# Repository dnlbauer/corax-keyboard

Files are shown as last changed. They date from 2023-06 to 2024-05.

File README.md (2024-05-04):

# Corax: A column-staggered fully-wireless split keyboard with scrollwheels.

- Choc-spaced, hot-swappable
- Two versions: with 56 or 54 keys
- Scrollwheel (EVQWGD001) on both sides
- Strong pinky stagger (0.66) and a 5 deg. pinky splay
- Fully wireless built for Nice!Nano + ZMK (no TRRS Jack)
- Nice!View support (5 pin connector)
- Reversible PCB
- 3d printable magnetic case, switchplate and MCU cover 

## Gallery

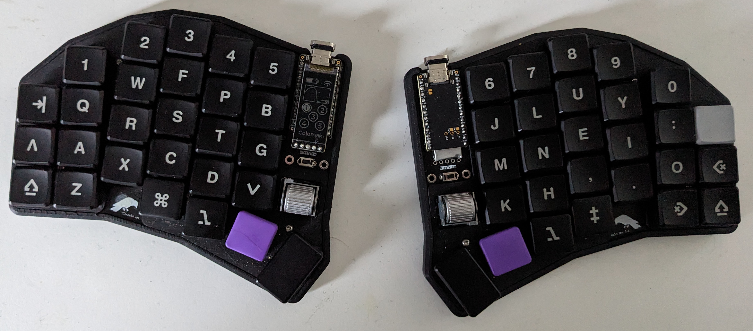
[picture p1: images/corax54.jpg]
corax54

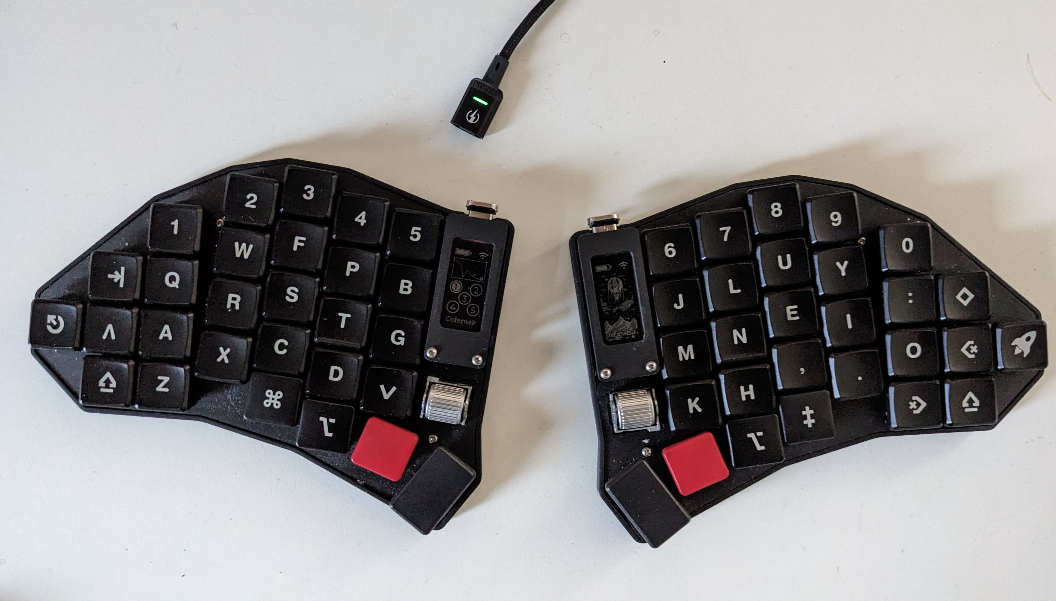
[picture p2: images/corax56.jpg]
corax56

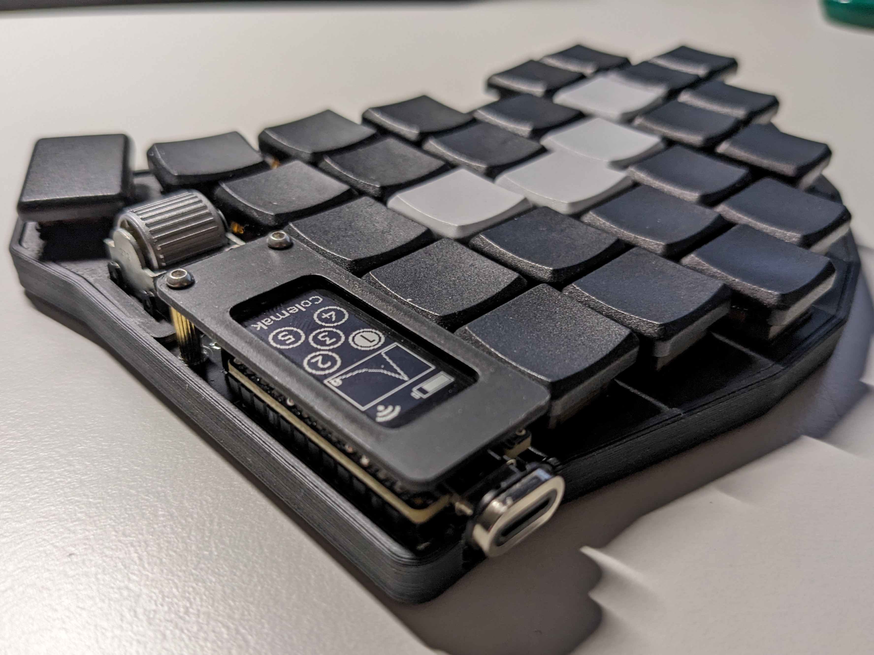
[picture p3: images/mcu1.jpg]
mcu1

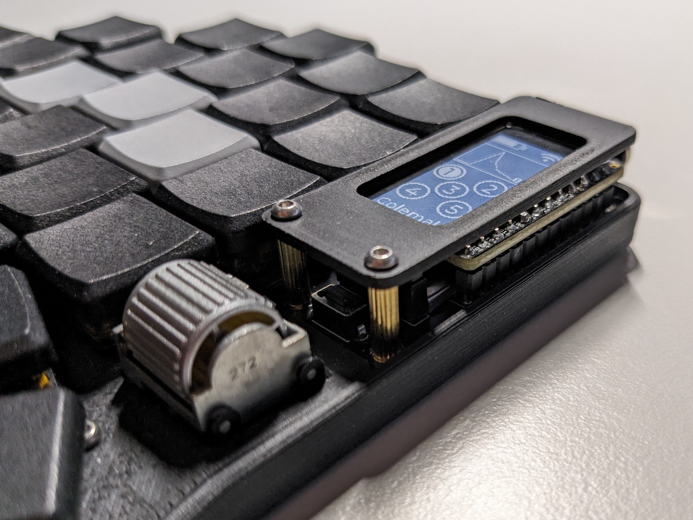
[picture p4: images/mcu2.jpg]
mcu2

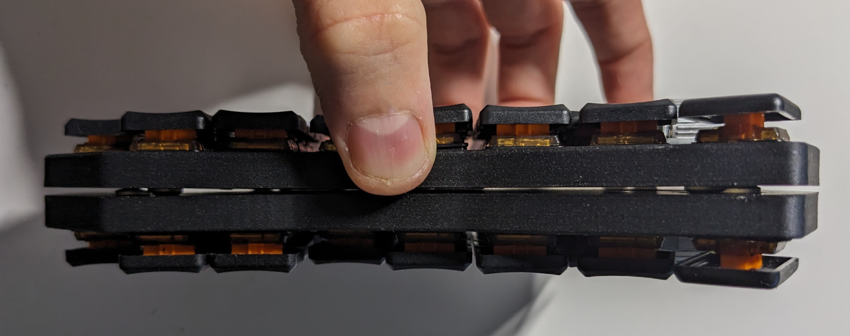
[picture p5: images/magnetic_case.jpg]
case

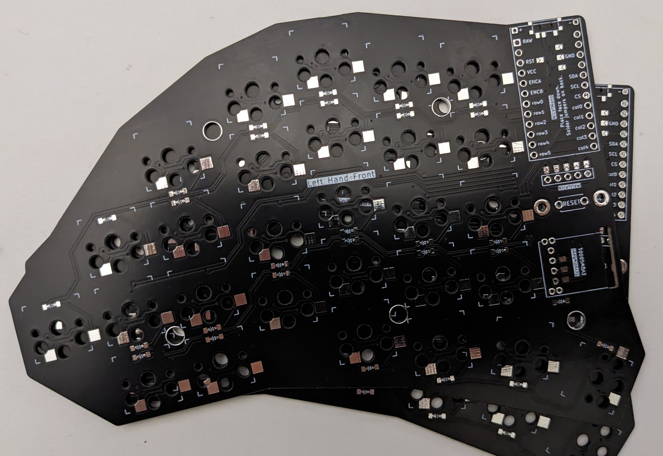
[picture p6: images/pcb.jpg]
pcb


## Corax56 vs Corax54

I initially designed the Corax56 (=56 keys) with 4 pinky keys. The upper key (usually mapped to ESC) was placed in a new column because I found it easier to reach horizontally than vertically.
Over the time, I realized that I am not using this button very often. The Corax54 was born as a more compact version where the pinky cluster misses this additonal column and has only 54 keys (2 less). This is the only difference between the two versions.

## Firmware

Natively supports [ZMK](https://zmk.dev/). The firmware for the Corax56 and Corax56 can be found in the submodule and is available here: https://github.com/dnlbauer/corax-zmk-config

## Build guide

[see here](./docs/BuildGuide.md)

## Standing on the shoulders of giants

- A great tutorial I referenced a lot by FlatFootFox: https://flatfootfox.com/ergogen-introduction/
- Lots of inspiration and ideas for this project came from these boards: [Choccy](https://github.com/sprengboard/choccy), [Sofle](https://github.com/josefadamcik/SofleKeyboard), [brain](https://github.com/Wesztman/brain), [spleeb](https://github.com/chrishoage/spleeb)

## License

This project is licensed under the MIT License - see the [LICENSE](LICENSE) file for details.

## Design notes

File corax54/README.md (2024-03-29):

# Corax54

## Bill of materials

**Essentials**:
| **Item** | **Count** | **Note** |
|---|---|---|
| Keyboard PCB | 2 | |
| Nice!Nano | 2 | |
| 12 pin headers and sockets | 4 | You can use through-hole diode legs as pins. Sockets spacing: 2.54mm, Socket height: Using minimal height sockets might not leave enough room to mount the battery under the MCU. 3DS1002-01-1*20V13-JK by CONNFLY are a good choice, but you can also use lower ones and longer legs instead. Spiltkb has a good [guide on mounting](https://docs.splitkb.com/hc/en-us/articles/360011263059).  |
| LiPo battery (301230) | 2 | 110mAh |
| Kailh Choc v1 switches (PG1350) | 54 | |
| Keycaps | 54 | |
| Kailh Choc hotswap sockets | 54 | |
| Encoder EVQWGD001 | 2 | |
| Diodes 1N4148W | 56 | for each key + encoder |
| Buttons | 2 | reset buttons; 2 pins through-hole, tactile, 3x6x4.3mm |
| Slider Switches | 2 | on/off switches; SMD, C128955 |
| USB-C Cable | 1 | for copying the firmware 

**Optional (Displays, 3d printed case)**:

| **Item** | **Count** | **Note** |
|---|---|---|
| Nice!View + mounts | 2 | |
| Switchplate | 2 | Height: 1.2mm; either 3d printed or cut pcbs. [stl](./3dprints/switchplate/) |
| Case (Left + Right) | 1 | see [here](./3dprints/case/). |
| Silicone feet | 8 | |

## Firmware

The firmware repository can be found here: [https://github.com/dnlbauer/corax54-zmk-config](https://github.com/dnlbauer/corax54-zmk-config).

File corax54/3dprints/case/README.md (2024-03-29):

# 3d printed keyboard case

Designed to hold 4 10x1mm magnets to hold the two halves together for transport.

## Preview

| Top | Front |
|-----|---|
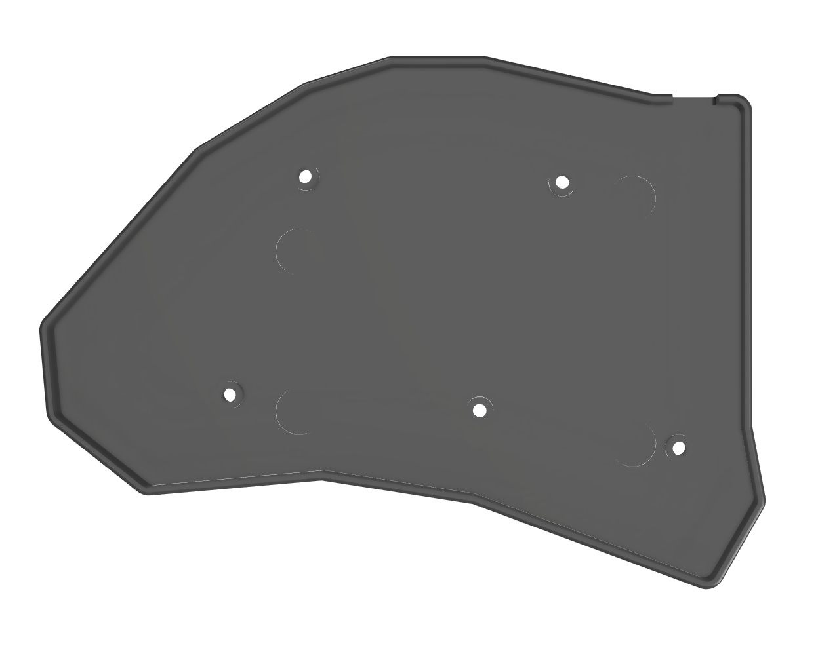
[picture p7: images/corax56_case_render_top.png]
top
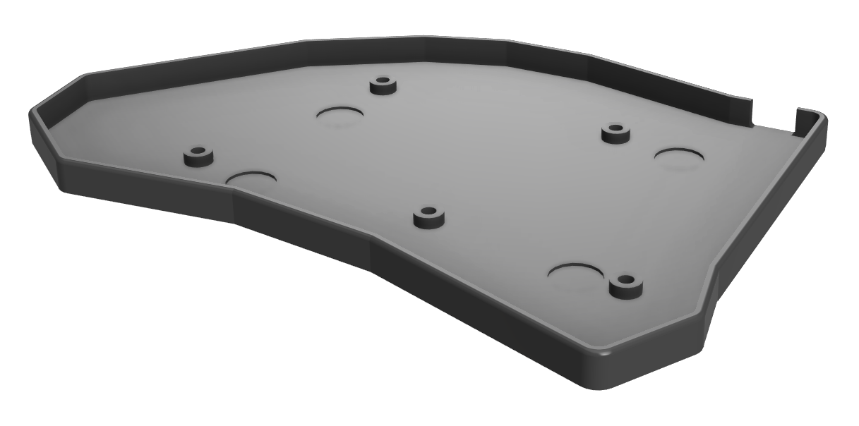
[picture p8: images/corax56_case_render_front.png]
front
|  |  |

## Bill of Materials

| Item | Count | Note |
|---|---|---|
| Printed case left + right | 1 | |
| Printed MCU cover | 1 |
| Magnets | 8 | round, 10x1mm |
| Case screws | 10 | M2*6 |
| Threaded inserts | 10 | M2*3 |
| Silicone feet | 8 | |
| Threaded brass standoffs | 4 | 10mm, M2 |
| MCU Cover screws | 8 | M2*4 |

## Printing

- layer height: 0.2mm
- wall thickness: 0.8mm
- infill: doesnt matter
- supports: not needed

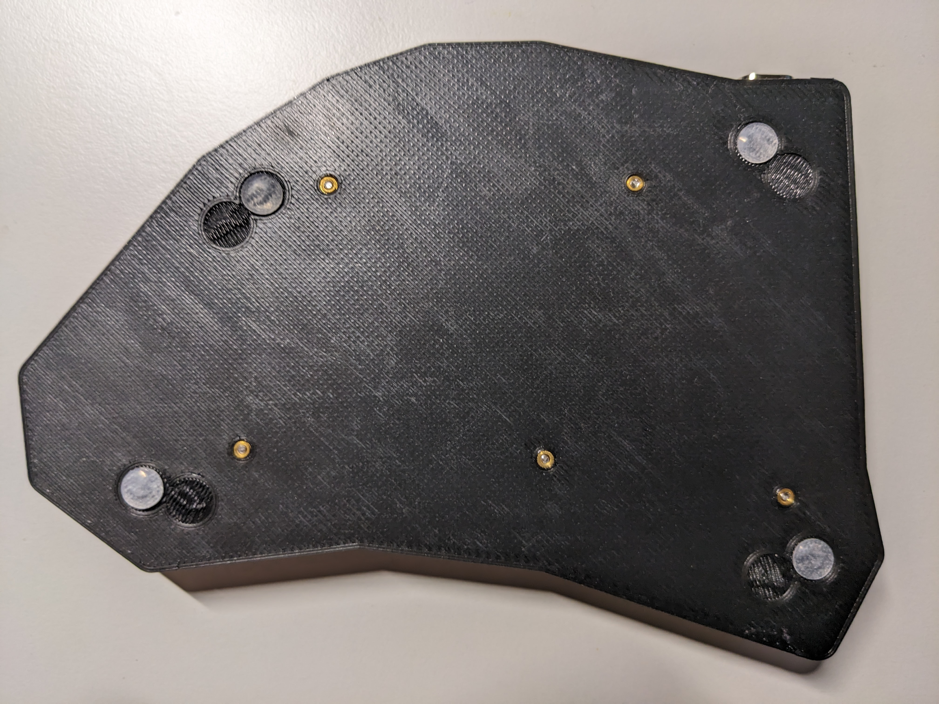
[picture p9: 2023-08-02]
images/case_back.jpg

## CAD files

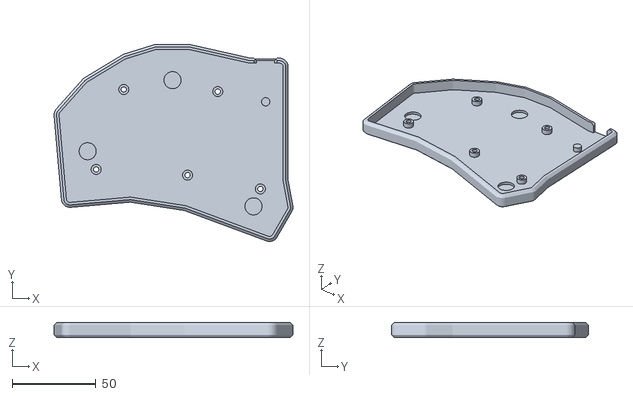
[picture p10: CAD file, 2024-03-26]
corax54/3dprints/case/case_left.stl
142.4 x 117.3 x 8.70

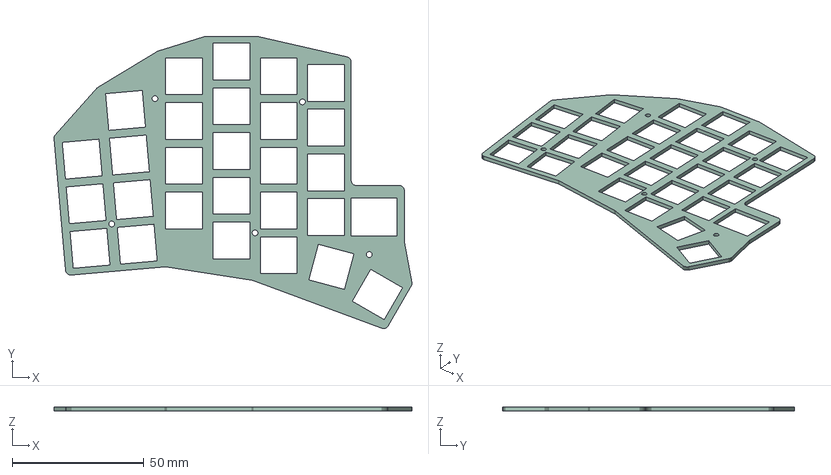
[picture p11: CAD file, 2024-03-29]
corax54/3dprints/switchplate/switchplate.step
136.0 x 110.9 x 1.60 mm

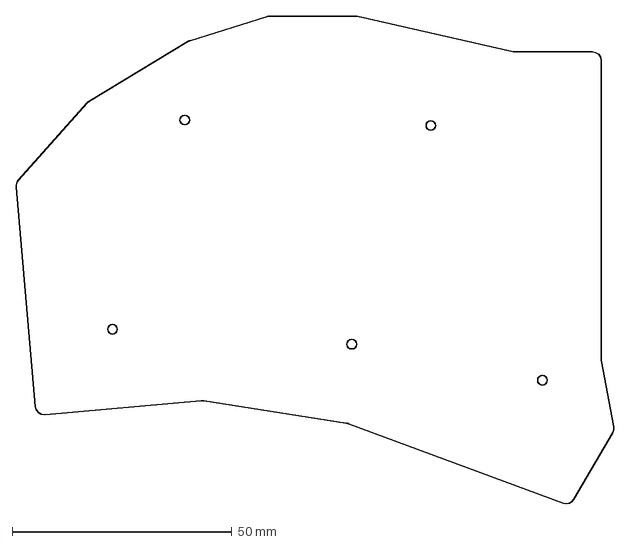
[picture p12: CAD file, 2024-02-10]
corax54/pcbs/outlines/case.dxf
136.1 x 111.2 mm

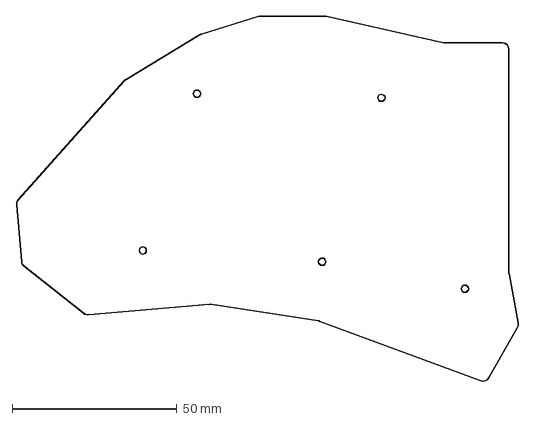
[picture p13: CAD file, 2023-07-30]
corax56/pcbs/outlines/case.dxf
152.5 x 111.2 mm

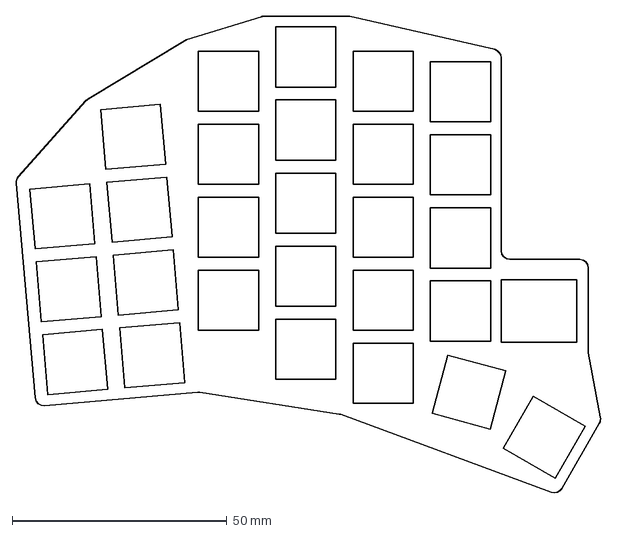
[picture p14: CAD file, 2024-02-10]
corax54/pcbs/outlines/switchplate.dxf
136.1 x 111.2 mm

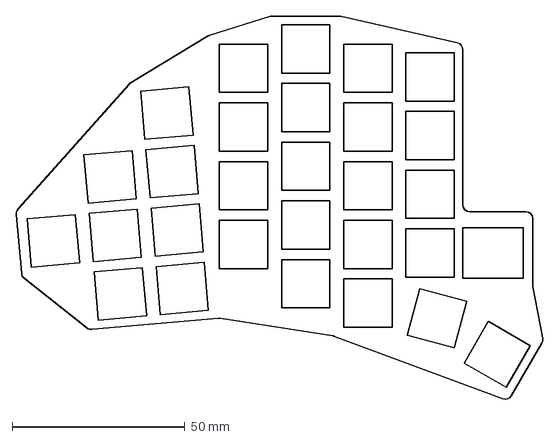
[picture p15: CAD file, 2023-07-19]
corax56/pcbs/outlines/switchplate.dxf
152.5 x 111.2 mm

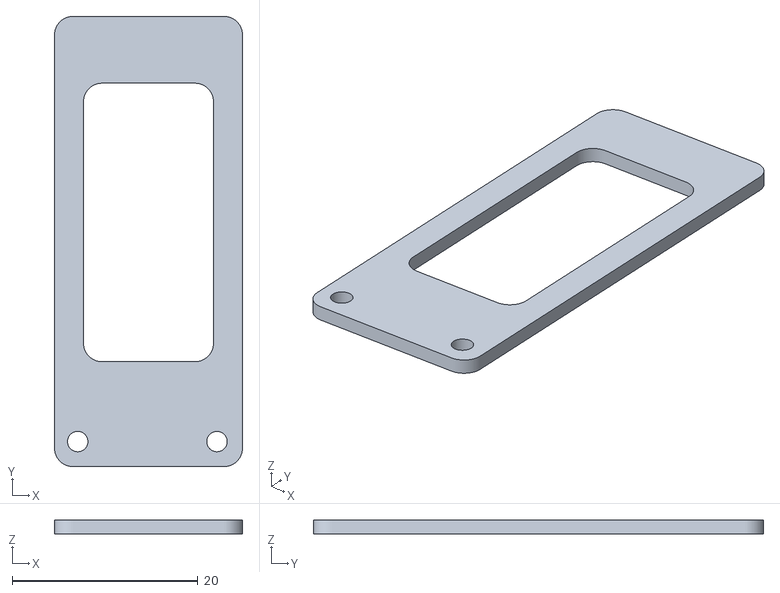
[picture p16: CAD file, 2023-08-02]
corax54/3dprints/case/mcu_cover.stl
20.2 x 48.5 x 1.50

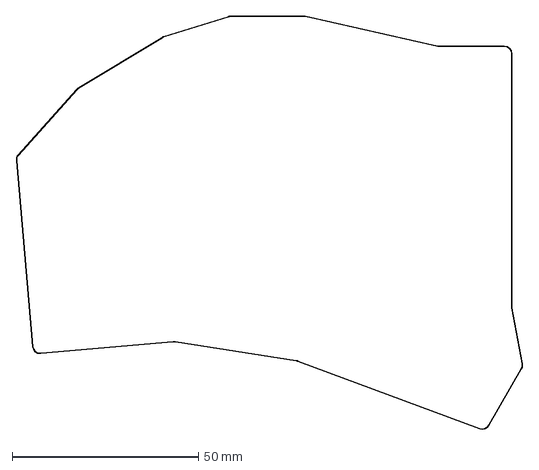
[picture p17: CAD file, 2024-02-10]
corax54/pcbs/outlines/board.dxf
136.1 x 111.2 mm

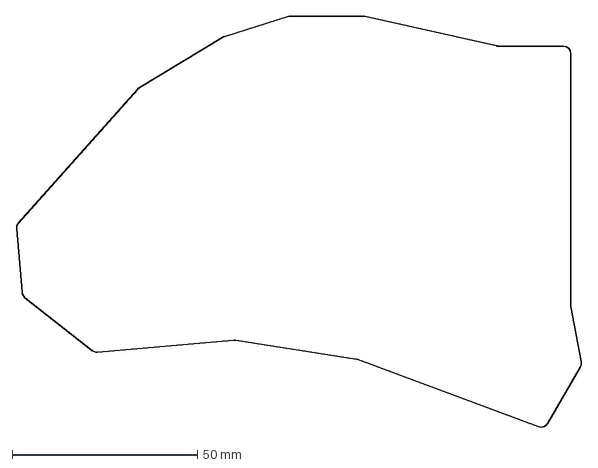
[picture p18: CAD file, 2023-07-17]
corax56/pcbs/outlines/board.dxf
152.5 x 111.2 mm

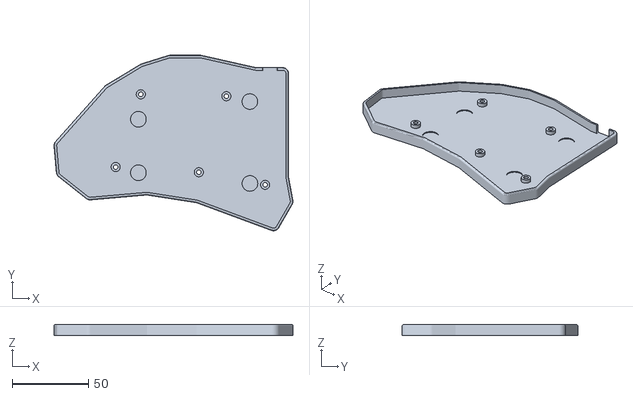
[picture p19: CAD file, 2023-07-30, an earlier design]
corax56/3dprints/case/case_left.stl
156.4 x 114.9 x 7.20

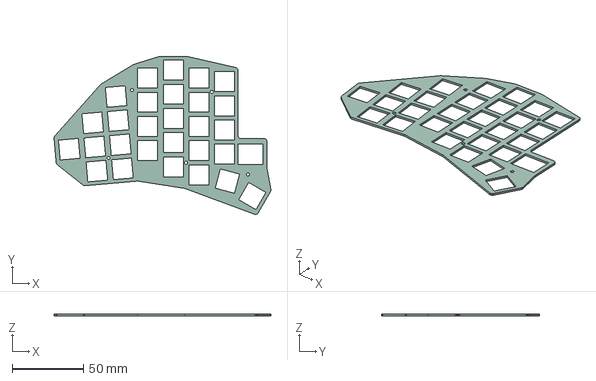
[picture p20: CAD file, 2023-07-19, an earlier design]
corax56/3dprints/switchplate/switchplate.step
152.4 x 110.9 x 1.20 mm

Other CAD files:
corax54/3dprints/case/case_right.stl
corax56/3dprints/case/case_right.stl
corax54/3dprints/case/case.f3z
corax54/3dprints/case/mcu_cover.f3z
corax54/3dprints/switchplate/switchplate.stl
corax56/3dprints/case/case.f3z
corax56/3dprints/switchplate/switchplate.stl

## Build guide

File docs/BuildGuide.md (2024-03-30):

# Build Guide

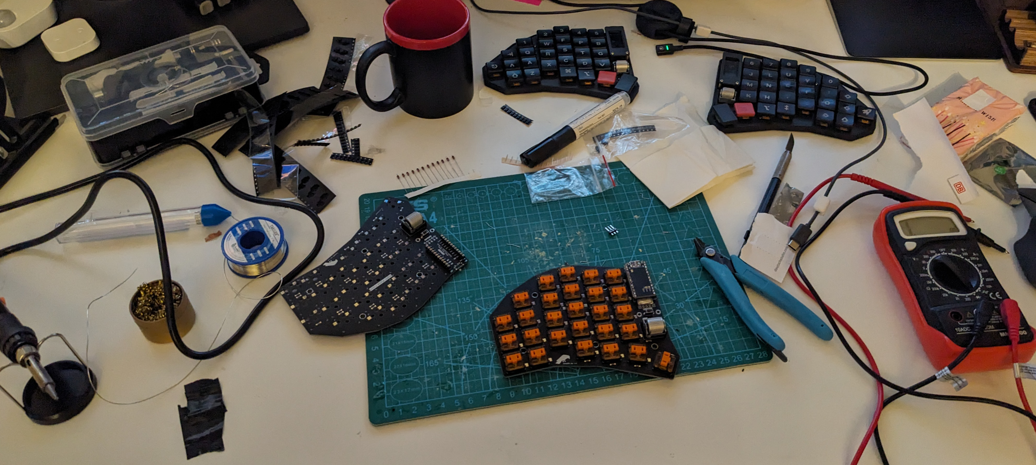
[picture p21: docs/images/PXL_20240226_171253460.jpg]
Messy desk


This guide describes the process of building the Corax54. For the Corax56, the build process is very similar and this guide should be easy to adopt to it.

Disclaimer:
This guide is written from the perspective of someone who already build some keyboards. It is probably not very beginner-friendly. There are many tricks and techniques for soldering and assembling keyboards that are not covered in detail. If this is your first build, I strongly recommend reading one or two more comprehensive guides on other keyboards that offer more detailed instructions first. Doing so will help you to avoid common pitfalls. A great guide I can suggest is the one for the sofle: 
https://josefadamcik.github.io/SofleKeyboard/build_guide_choc.html

## Ordering PCBs

To order the PCBs, grab the relevant zip file with the gerber files from the [releases page](https://github.com/dnlbauer/corax-keyboard/releases) (named corax*-gerbers.zip) and send them to the PCB etching service of your choice. I personally can recommend [JLCPCP](https://jlcpcb.com/). I recommend these settings:

|||
|---|---|
| Layers | 2 |
| PCB Thickness | 1.6 mm |
| Surface Finish | LeadFree HASL |
| Via Covering | Tented |
| Board Outline Tolerance | +/- 0.2 mm(Regular) |

## Buiding the Keyboard

You need two pcbs: for the right and left hand side. Make sure to not mix them up during the build process. If this guide says "front side" and you are building the left hand side of the keybaord, you are meant to work on the side that says "Left Hand Front" on it. In this caes, the side saying "Right Hand Front" is considered to be the back side. 

A good strategy is to mark the intended front side of each side with a post-it or a piece of tape. Before each step, make sure you are working on the correct side to not mess things up!

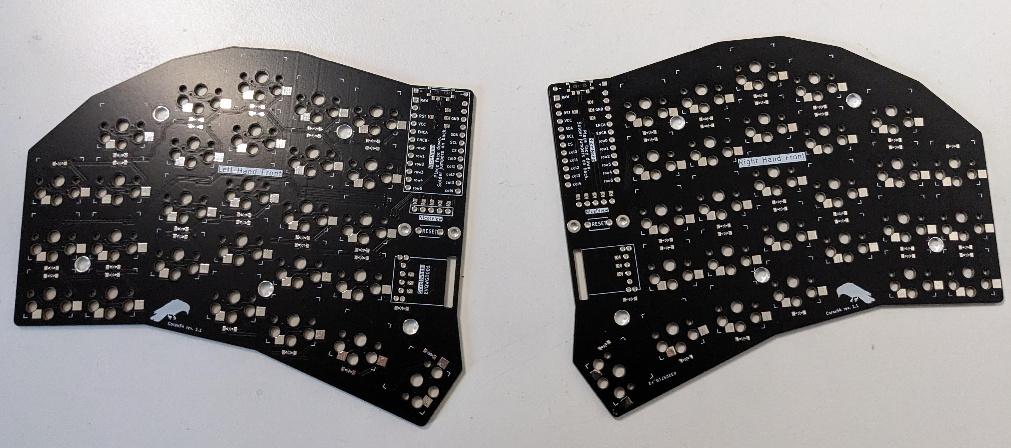
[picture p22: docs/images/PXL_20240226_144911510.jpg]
PCBs


### Jumper

There are 12 Jumpers on each side of the board. They make the MCU pin holes reuseable for the left and right version. You need to solder the pins **ONLY on the back of the pcb**. I.e if you are working on the left side of the keyboard, the front side is labeled "Left Hand Front" and you are required to only solder the jumpers on the side that is labeled "Right Hand Front". This is crucial! If you solder the pins on the wrong side, the keyboard will not work (and you might even short the MCU and break it!).

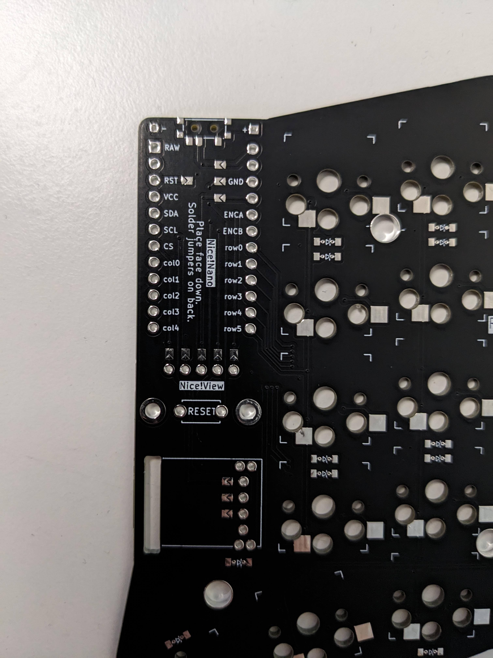
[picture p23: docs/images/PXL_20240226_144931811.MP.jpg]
Jumper unsoldered


Solder all jumpers circled in red. There are a total of 12 jumpers at 3 positions for the MCU, display and the scrollwheel.

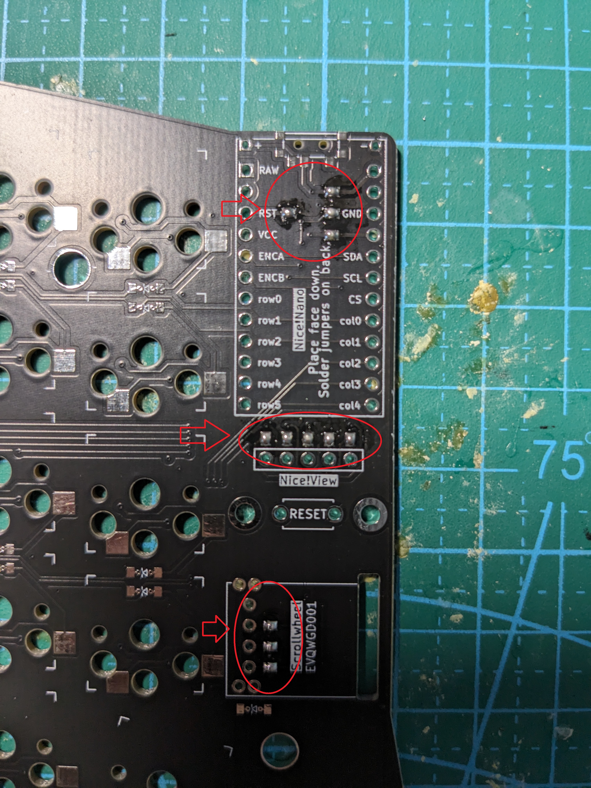
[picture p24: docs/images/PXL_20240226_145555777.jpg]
Jumper


### MCU sockets

Solder in the MCU sockets. I usually tape them into position, then flip the board and solder them while the tape holds them in place.

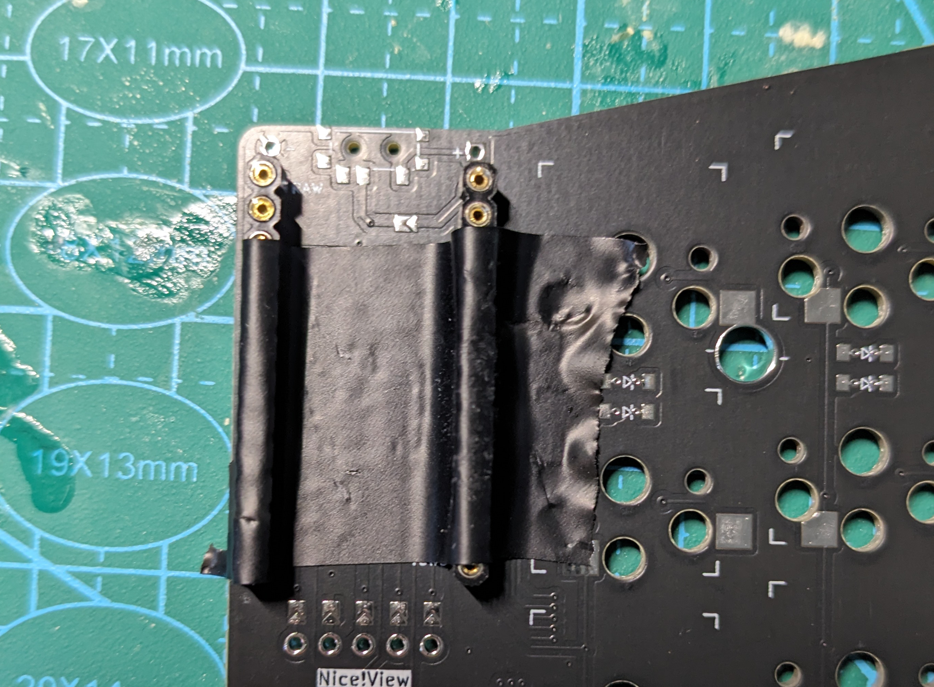
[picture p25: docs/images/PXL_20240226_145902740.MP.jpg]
MCU Sockets front


Here you can see the back side with the sockets soldered in place and the soldered jumpers:

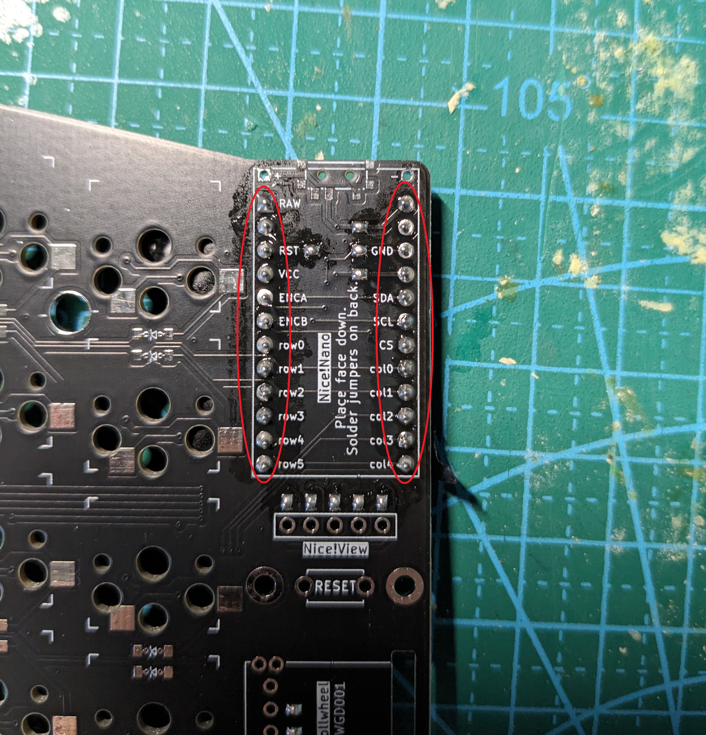
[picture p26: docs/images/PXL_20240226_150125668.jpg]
MCU Sockets back


### On/Off switch and reset button

The On/Off switch belongs to the back side of the board to leave enough room for the battery between the MCU and board. It has 7 legs, but only the 3 marked legs are required for the board to work. If you want, you can also solder the other pins of the switch; it doesn't matter.

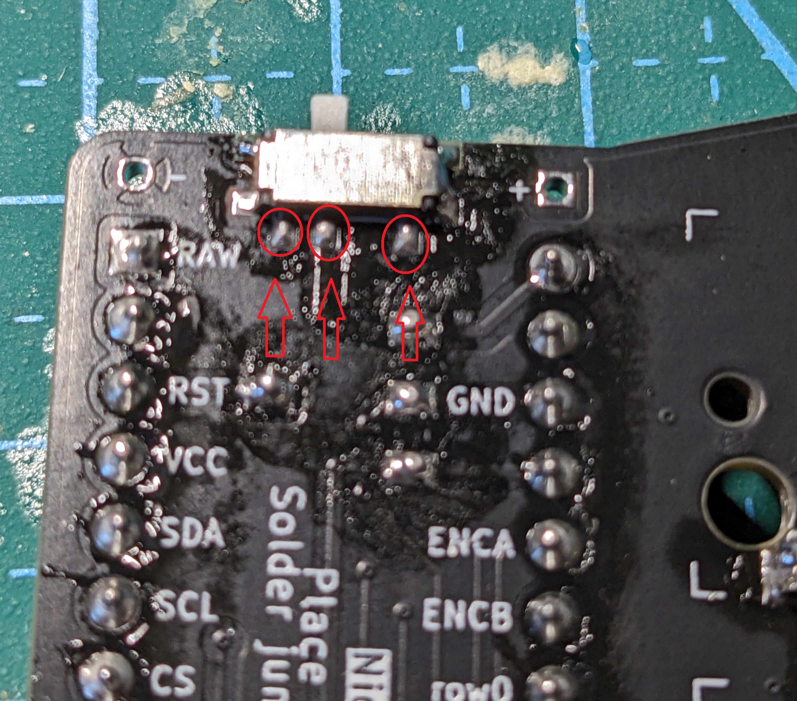
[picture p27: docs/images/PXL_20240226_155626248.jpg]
On off switch


The 2-pin reset button can now be soldered too. Put it in from the front side and solder on the back. The orientation does not matter.

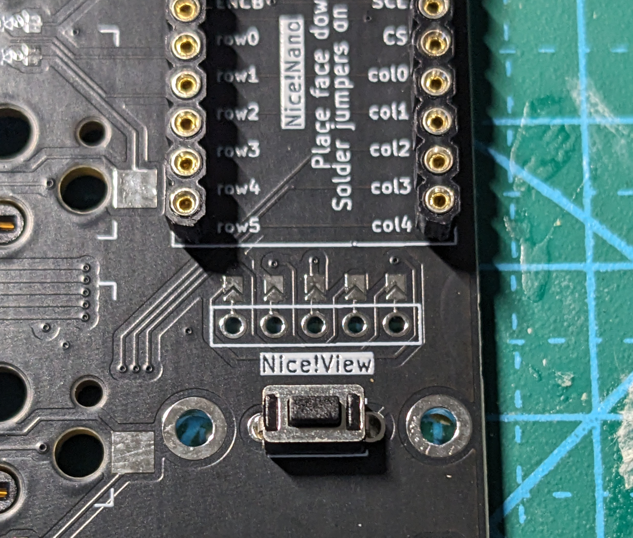
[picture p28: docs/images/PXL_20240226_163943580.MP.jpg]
Reset front

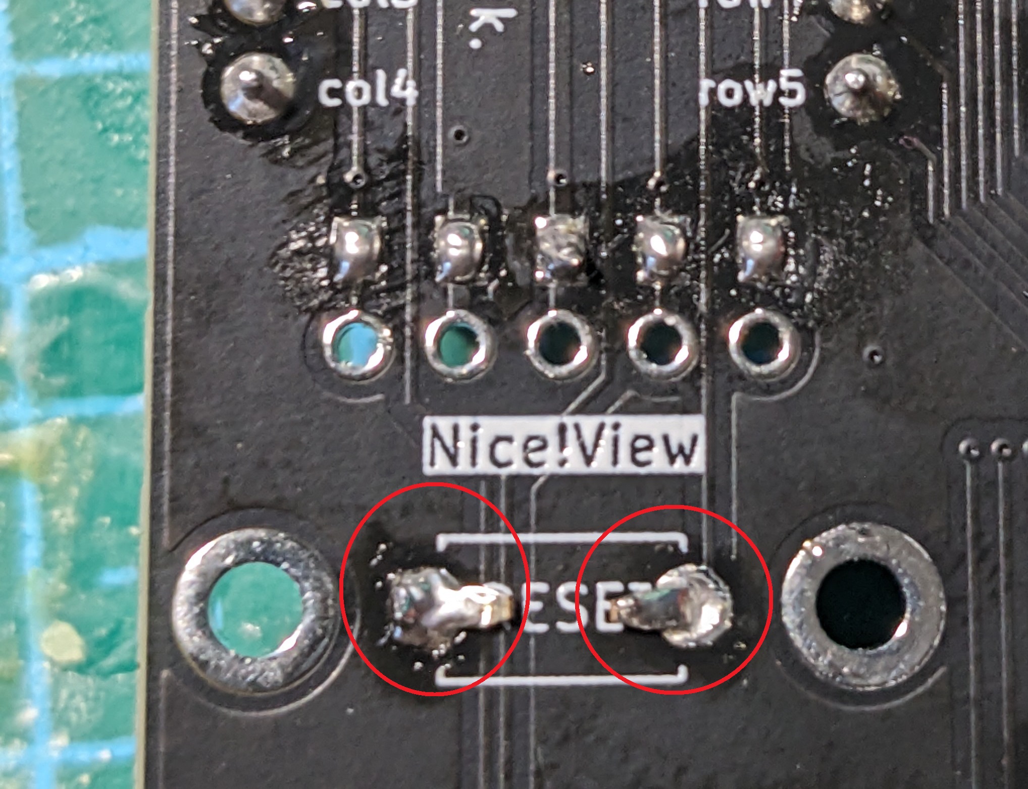
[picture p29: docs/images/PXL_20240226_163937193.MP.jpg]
Reset back


### Scroll wheel

Before soldering, you need to cut away at least the one foot on the left of the scrollwheel in the picture below. It is not needed and there is no hole for it on the board.

I also cut away the overhangs on the long right edge to make it easy to place the scrollwheel on the board. The soldered pins should be sturdy enough to hold the scrollwheel in place without the overhanging bits. There is a risk of breaking one of the pins otherwise because it is a very tight fit.

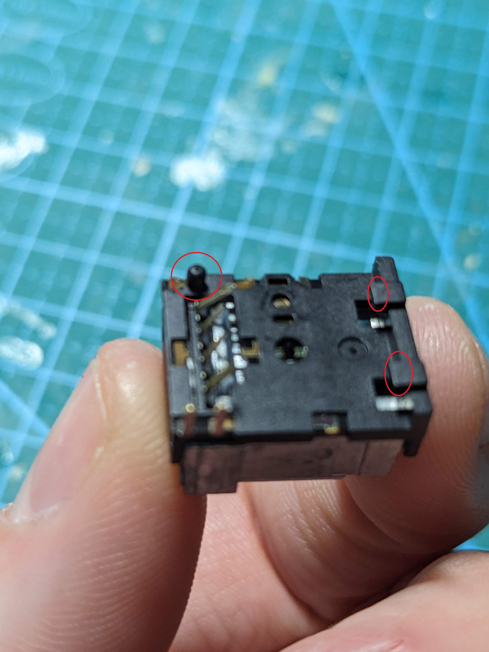
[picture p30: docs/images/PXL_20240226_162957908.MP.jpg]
scrollwheel


### Hotswap socket and diodes

There are a total of 54 hotswap sockets and 55 diodes (one for each key + scrollwheel) per side. Both belong to the **back side** of the board. For the diodes, the orientation is important! Each diode has a marking (an arrow or a white line) that must be oriented towards the pointy arrow that is shown on the board. If you are unsure, google how to place diodes first and get used to the terminology first!

Image of the back and front side with all components in place:
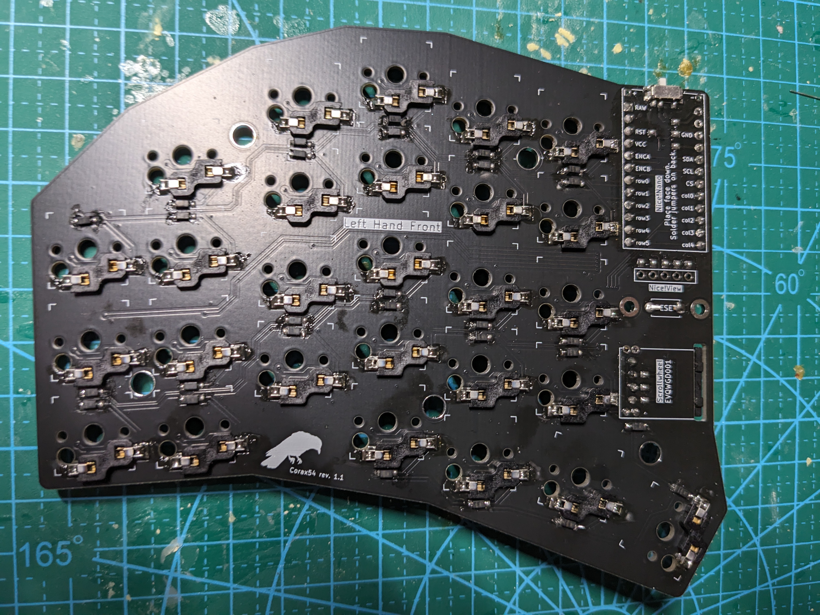
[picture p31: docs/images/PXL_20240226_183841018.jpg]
Components Back

Components Front

### Battery

Now it is time to add the LiPo battery. It is intended to be placed on the front side below the MCU, but in theory, it is also possible to add it to the back side. Just make sure the polarity matches the markings on the front side of the board. Usually, black means (-) and red means (+).

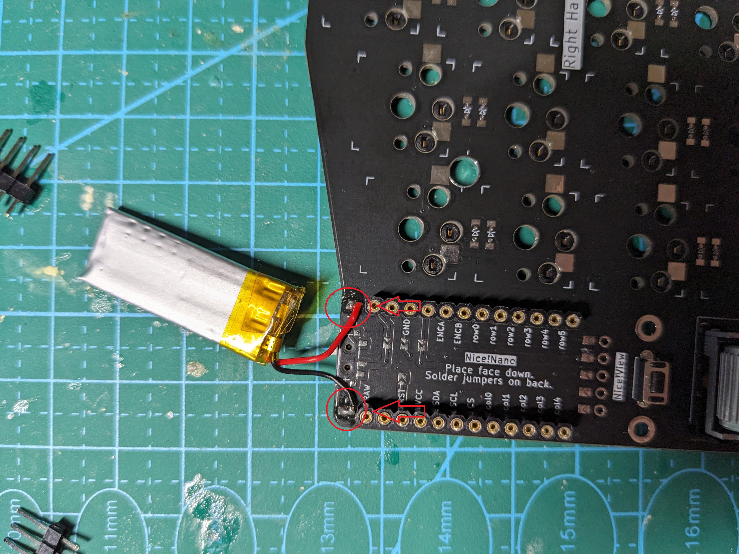
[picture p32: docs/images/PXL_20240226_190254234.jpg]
Battery Soldered

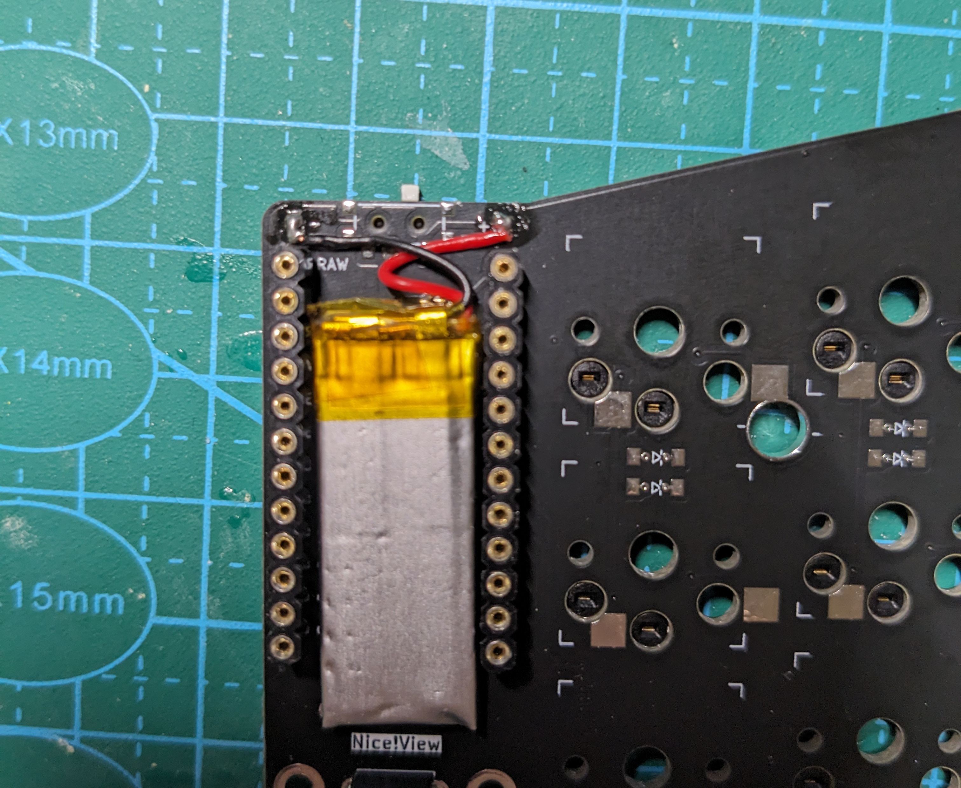
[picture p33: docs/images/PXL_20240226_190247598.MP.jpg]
Battery Positioned


### MCU

Add the MCU and solder the pins to it. The MCU belongs to the front side facing down. If you bought the correct sockets, there should be enough room to hide the battery under it. If there is not enough room, solder the pins in such a way that there is enough room below.

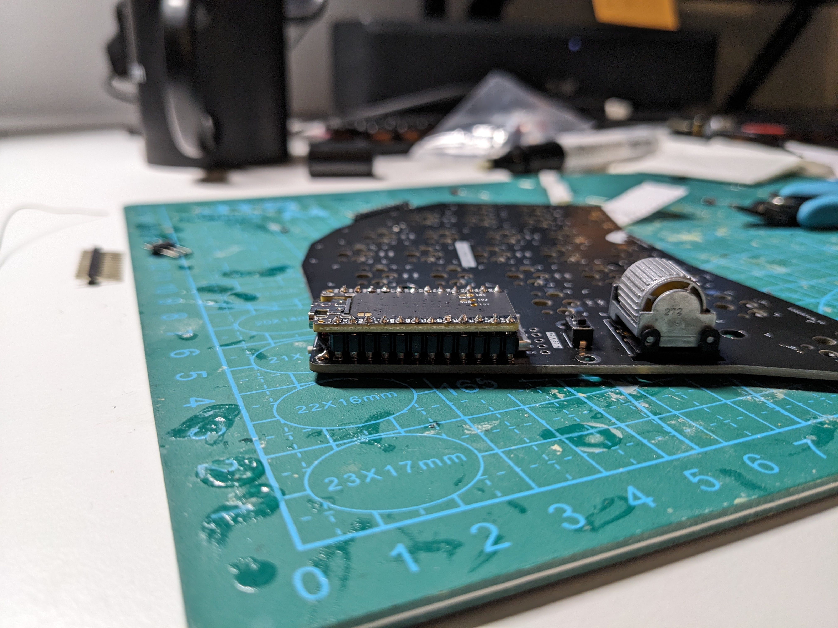
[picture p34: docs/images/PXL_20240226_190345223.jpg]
MCU Top

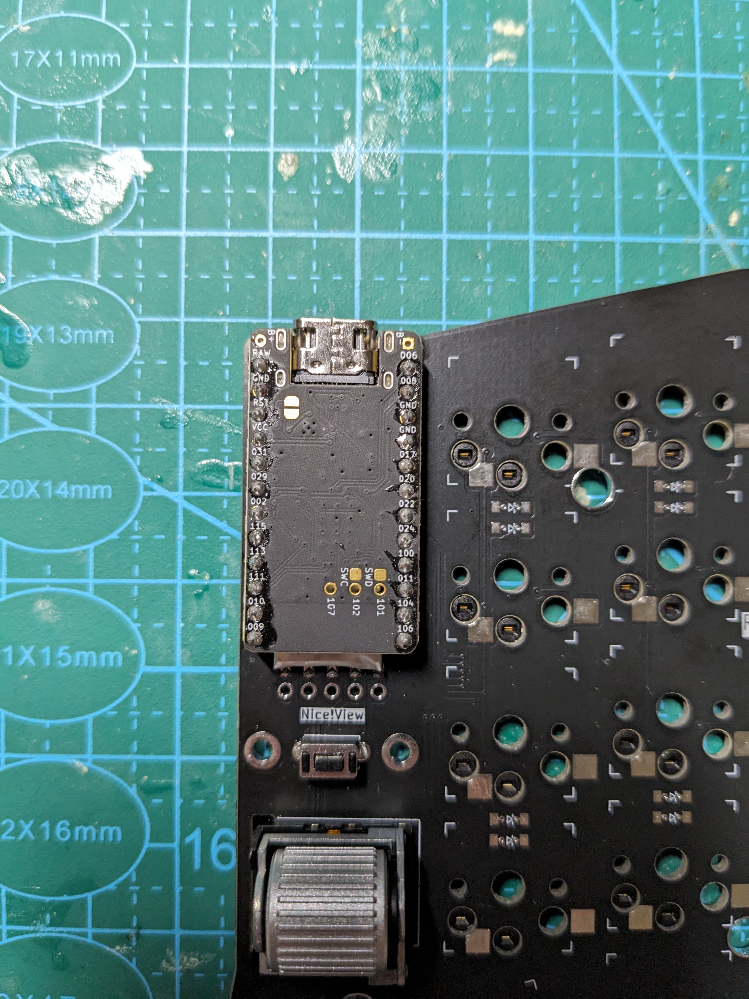
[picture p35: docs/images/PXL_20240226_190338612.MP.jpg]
MCU Side


### Add switches and keycaps

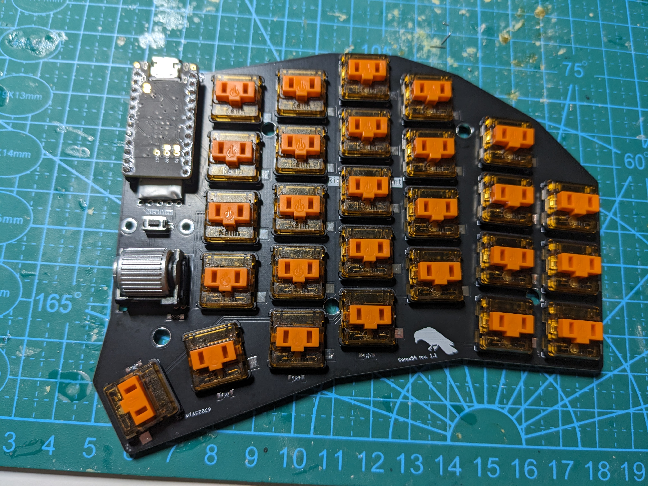
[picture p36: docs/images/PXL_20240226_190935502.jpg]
Switches

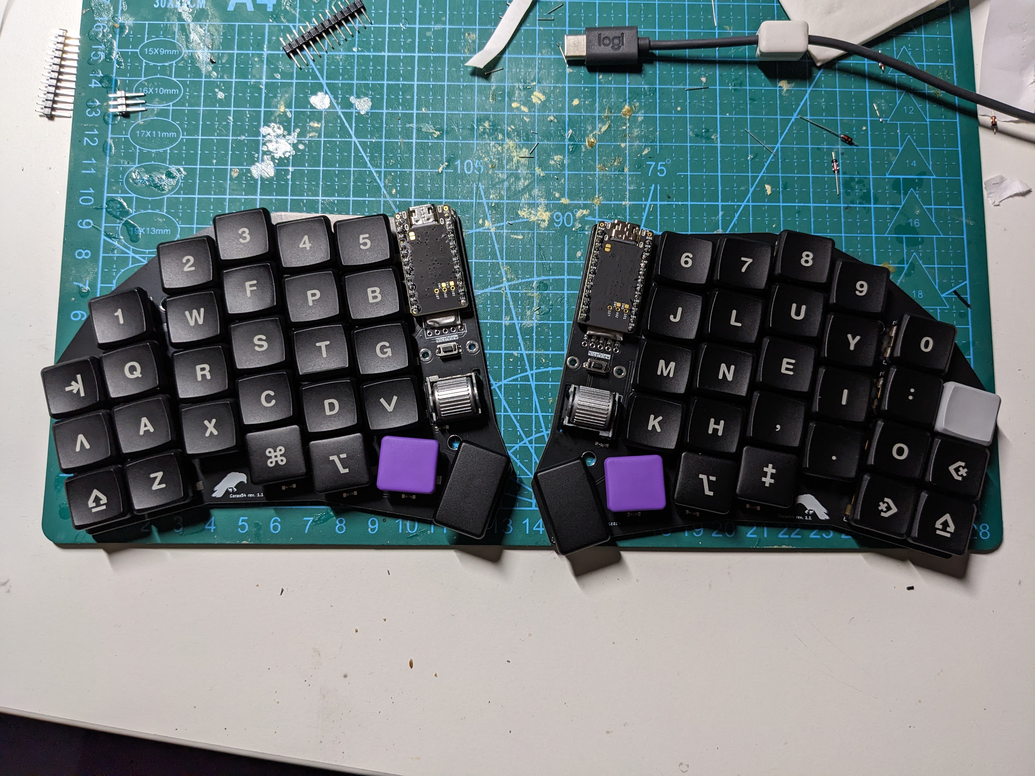
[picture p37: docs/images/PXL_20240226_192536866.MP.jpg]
Keycaps


## Display (Nice!View)

TODO

## 3d printed Case

TODO

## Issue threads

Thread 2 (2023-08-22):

Battery and Switch Locations?

ErichKinder, 2023-08-22:
Any chance you could post a picture or diagram for which side the switch and which points the battery are soldered to? It's not super clear from the PCB alone.

dnlbauer, 2023-08-22:
The switch should be soldered on the opposite side (the bottom side) of the pcb. For the battery, they should be soldered to the uppermost pins on the board which are marked as + and -. I store the battery sandwhiched between the MCU and the board, but you could also solder it on the bottom side and hide it under the keyboard i guess. Just make sure you get the polarity right. I heard of cases where the red wire was not on the +.

Here are some pictures that show how I placed things.

Let me know if this helps!
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

Closed 2023-08-22.

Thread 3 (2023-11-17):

Version with less thumb keys?

zawnk, 2023-11-17:
First, thanks for creating this keyboard an open-sourcing it :) I'm strongly considering building it, but I have a brief question: is there any realistic chance for an alternative version with only two instead of four thumb keys (dropping the left two)? (I also wouldn't need the single key at the outer edge but that's out of the way)

I assume chances to be not that high, but figured that asking before ordering the PCBs wouldn't hurt :)

dnlbauer, 2023-11-17:
Hi,

I'm planning to make a version with less thumbnails right now. PRs are welcome though if you want to give it a shot yourself! :)

I thought about making a version without the outer key for some time since I'm rarely using it. However when and if this will happen, I can't say. So I suggest not not wait for this to happen.

zawnk, 2023-11-17:
> I'm planning to make a version with less thumbnails right now. PRs are welcome though if you want to give it a shot yourself! :)

I wish, sadly I know near to nothing about KiCad/designing the PCB and even less about adjusting the case model :D

> So I suggest not not wait for this to happen.

Does this apply to both the less thumb keys _and_ the single key? I'm not particularly in a rush, I still need to order diodes and 1-2 other small things from China :)

dnlbauer, 2023-11-17:
> I wish, sadly I know near to nothing about KiCad/designing the PCB
This was me before starting the project. 😉

> Does this apply to both the less thumb keys and the single key?
Both. I'm not planning to work on less thumb keys and for removing the outer button: I'm playing with the thought to do this but don't know when I find enough time to tackle this. Likely not this year.

zawnk, 2024-04-07:
I've now ordered the pieces for the 54 key version, that's good enough for me, I'll just ignore the extra thumb keys (or just not solder any switches on it) :) So if you think it's unlikely that you create even more versions, feel free to close this issue.

PS: I've started looking into ergogen thanks to you and referred your ergogen files a few times already at reddit when people had questions/needed examples! Life has kept me too busy to look deeply into it, but I will in the future :)

Closed 2024-04-08.

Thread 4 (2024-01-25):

Unable to get reset switch, battery on/off switch and encoder up/down working

soumilgurjar, 2024-01-25:
Thanks for making this fantastic keyboard! It's one of the few low-profile split keyboards with a number row out there with an aggressive stagger.

I have recently built two sets of this keyboard and I have run into the following issues on both of them:
- The reset switch does not work on either half. I am unable to put the nice!nano v2 into bootloader mode using it, and have to resort to directly shorting the appropriate pins twice to do so.
- The battery connected to the PCB does not work, i.e the battery on/off switch does not power the micro-controller. Therefore I have needed to directly connect the battery to the MCU.
- The encoder works but only on the key press, the up/down scroll of the encoder does not perform any action.

Could you perhaps help me diagnose the issues? Since the same issues have occured on both keyboard builds and the components work on other keyboards that I have built, I am wondering if there is possibly an issue with the PCB related to these aspects. Any input would be appreciated. Thanks!

Unrelated: What does the instruction on the PCB - 'Solder jumpers on back' - mean?

soumilgurjar, 2024-01-25:
I was able to figure it out soon after opening this issue. But I'll leave this here for future reference and close the issue. The solution to all those above issues is to solder the jumpers on the back side of each half. Putting a tiny blob of solder on each of the jumpers marked in red resolves all the issues.

If someone is using the nice!view, they would need to solder the corresponding jumpers as well.

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

dnlbauer, 2024-01-28:
Great to hear there is another Corax out there :) And even better to hear that you already figured it out.

These things are probably kinda hard to figure out unless you already built  a board that requires to solder jumpers. There are another 5 jumpers that are not marked in your picture where the nice nano connects (you only need them if you want to use a display).

For things like this, it would be really nice to have a good build guide. Mine is fully assembled but if someone ever starts a new build of a corax, it would be great to have some high detail step-by-step pictures to use for a tutorial! Read: Contributors welcome :)

zawnk, 2024-04-13:
> There are another 5 jumpers that are not marked in your picture where the nice nano connects (you only need them if you want to use a display).

Is there any harm in soldering the jumpers if you don't plan to use an OLED for now? (they're not available currently). It would be nice if I wouldn't have to disassemble everything and solder the OLED jumpers later when the OLED arrives.

dnlbauer, 2024-04-13:
Theres no harm if you solder them. You also don't have to disable oled in ZMK. ZMK doesnt care if there is a display connected or not and most of the battery power displaying requires will be the consumption of the display and not from the MCU calculating the display signal.

My suggestion is to solder the jumpers and leave the firmware as is unless you want to play with the firmware anyways.

Closed 2024-01-25.

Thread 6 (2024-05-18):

Right OLED is just blank?

zawnk, 2024-05-18:
My nice!views finally arrived and I've soldered them on. The left one immediately worked without me having to do anything, just turning the right half back on. The right side just stays 'off' or at least doesn't display anything and just stays white. The OLED itself isn't faulty, because it works on the left side just fine. Am I missing any configuration for ZMK or anything to get the right one to work? Do I have to do anything special to get it to work? The jumper pads are all soldered, I've double checked that.

Thanks for the help!

dnlbauer, 2024-05-18:
the oleds should not be affected by the firmware to my knowledge. maybe there is an issue with the soldering that leads to a short circuit and therefore the nice nano is not turning on? do you have a multimeter to measure if there are any shorts between the pins?

zawnk, 2024-05-18:
Mhhh, I just tested to make sure, tried:
- socket on the PCB top and bottom to see if the socket mount is working fine and that worked
- on the bottom side of the PCB I checked if there's a short between the pins so I checked if any of them are connected but that seemed fine (no connection between any pins)
- checked the top of the OLED with its pins that I've soldered on but they also seem to work fine (but the OLED works on the other half just fine so I was 99% sure this isn't the problem)

Also turned the right half on and off and the reset button, but that didn't help either, the screen is still off

zawnk, 2024-05-23:
I've tested the soldering on the display and its sockets again and the continuity seems fine with no shorts.

But I've used the multi to check the voltage between VCC and GND and on the left side it's 3.2-3.3V and the right side shows 0 (even on the bottom side of the PCB). The jumpers are soldered on the bottom so that shouldn't be it. Are there any other pins that I could've missed?

zawnk, 2024-05-23:
Turns out I needed to use `&ext_power EP_TOG` a few times and just toggle the external power supply for a bit for a reason that's not clear to me  :D

So if someone else has this problem: despite what the docs say, just bind that functionality and toggle the power and and off for a bit. At first, it only turned my left side off as well and nothing changed on the right, but after about a minute the right side turned on as well seemingly randomly. Now it seeems to work.

A bit quirky but I'll take it :)

Closed 2024-05-23.

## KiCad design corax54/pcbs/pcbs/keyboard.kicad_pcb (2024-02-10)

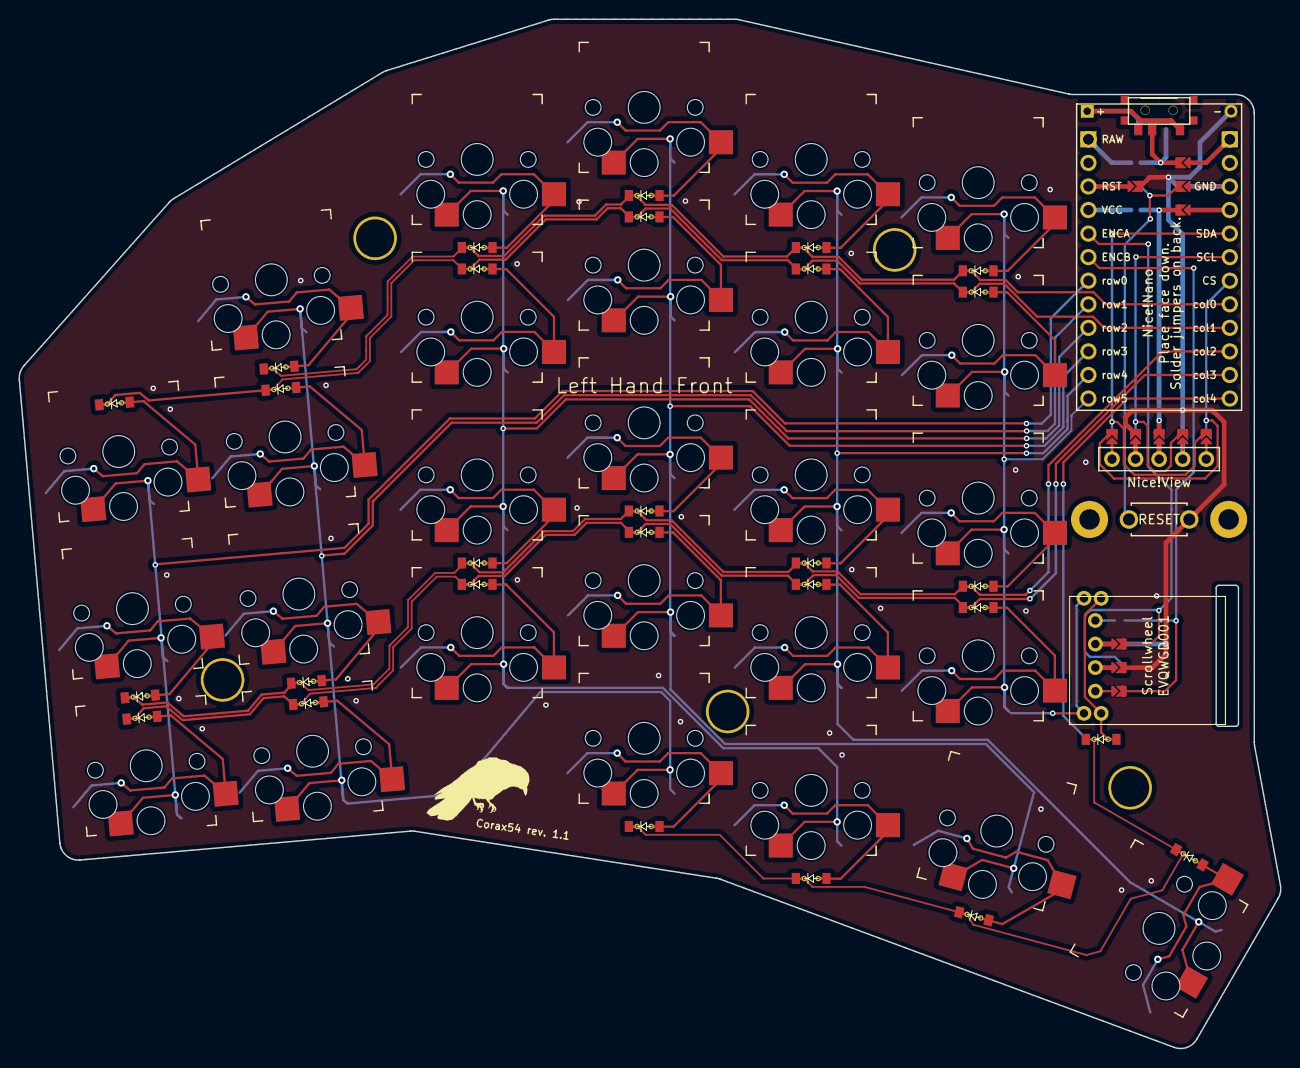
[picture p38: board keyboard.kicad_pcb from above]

Board: 2 copper layers, 136.0 x 110.9 mm, 90 parts (0 on the bottom side), 60 nets.

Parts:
D1, D2, D3, D4, D5, D6, D7, D8, D9, D10, D11, D12, D13, D14, D15, D16, D17, D18, D19, D20, D21, D22, D23, D24, D25, D26, D27, D28: ComboDiode
J1, J2, J3, J4, J5, J6, J7, J8, J9, J10, J11, J12, J13, J14, J15, J16, J17, J18, J19, J20, J21, J22, J23, J24: Jumper
MCU1: ProMicro
Nice!View1: niceview_headers
S1, S2, S3, S4, S5, S6, S7, S8, S9, S10, S11, S12, S13, S14, S15, S16, S17, S18, S19, S20, S21, S22, S23, S24, S25, S26, S27: PG1350
T1: SPDT_C128955
_1: ResetSW
_2, _3, _4, _5, _6, _7, _8: Hole

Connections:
CS: J19.2, J24.2, MCU1.19
ENCA: J3.2, J6.2, MCU1.5
ENCA_GND: J3.1, J5.1
ENCB: J1.2, J4.2, MCU1.6
GND: J2.2, J5.2, J10.2, J14.2, J18.2, J23.2, _1.2
GND_ENCA: J2.1, J6.1
GND_RST: J10.1, J12.1, MCU1.15
GND_VCC: J13.1, MCU1.16
NN_CS_SDA: J19.1, J20.1, Nice!View1.1
NN_GND_SCL: J18.1, J21.1, Nice!View1.1
NN_SCL_GND: J16.1, J23.1, Nice!View1.3
NN_SDA_CS: J15.1, J24.1, Nice!View1.4
NN_VCC: J17.1, J22.1, Nice!View1.2
P1_RAW: J11.1, MCU1.13
RAW: J7.2, J11.2, T1.2
RAW_P1: J7.1, MCU1.1
RST: J8.2, J12.2, _1.1
RST_GND: J8.1, J14.1, MCU1.3
SCL: J16.2, J21.2, MCU1.18
SDA: J15.2, J20.2, MCU1.17
VCC: J9.2, J13.2, J17.2, J22.2
VCC_GND: J9.1, MCU1.4
col0: D3.1, D5.1, D8.1, D11.1, D13.1, MCU1.20
col1: D16.1, D18.1, D20.1, D22.1, D24.1, D26.1, MCU1.21
col2: D1.1, D2.1, D4.1, D7.1, D10.1, D12.1, MCU1.22
col3: D15.1, D17.1, D19.1, D21.1, D23.1, D25.1, MCU1.23
col4: D6.1, D9.1, D14.1, D27.1, D28.1, MCU1.24
index_bottom: D23.2, S18.2
index_home: D10.2, S19.2
index_mod: D9.2, S17.2
index_num: D11.2, S21.2
index_top: D24.2, S20.2
inner_bottom: D25.2, S22.2
inner_home: D12.2, S23.2
inner_num: D13.2, S25.2
inner_top: D26.2, S24.2
layer_cluster: D14.2, S26.2
middle_bottom: D21.2, S13.2
middle_home: D7.2, S14.2
middle_mod: D6.2, S12.2
middle_num: D8.2, S16.2
middle_top: D22.2, S15.2
outer_bottom: D15.2, S1.2
outer_home: D1.2, S2.2
outer_top: D16.2, S3.2
pinky_bottom: D17.2, S4.2
pinky_home: D2.2, S5.2
pinky_num: D3.2, S7.2
pinky_top: D18.2, S6.2
ring_bottom: D19.2, S8.2
ring_home: D4.2, S9.2
ring_num: D5.2, S11.2
ring_top: D20.2, S10.2
row0: MCU1.7, S1.1, S2.1, S3.1
row1: MCU1.8, S4.1, S5.1, S6.1, S7.1, S12.1
row2: MCU1.9, S8.1, S9.1, S10.1, S11.1, S17.1
row3: MCU1.10, S13.1, S14.1, S15.1, S16.1, S26.1
row4: MCU1.11, S18.1, S19.1, S20.1, S21.1, S27.1
row5: MCU1.12, S22.1, S23.1, S24.1, S25.1
space_cluster: D27.2, S27.2

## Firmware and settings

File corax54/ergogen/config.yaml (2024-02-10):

units:
  kx: cx  # cx=18
  ky: cy  # cy=17
  mbkx: 17.5
  mbky: 16.5
  padding: 2
  px: kx+padding
  py: ky+padding
  mcu_height: 34
  mcu_width: 18
  # distance keys to mcu
  mcu_padding: 1.5
  scrollwheel_width: 17
  scrollwheel_height: 14
  screw_diameter: 4.7
  screw_hole: 4.1
  screen_screw_diameter: 4
  screen_screw_hole: 2.2
  switchplate_switch_cutout: 14
  switchplate_scrollwheel_cutout_x: 17.5
  switchplate_scrollwheel_cutout_y: 14.5
  switchplate_screw_diameter: 3.3
  switchplate_screw_hole: 2.2
points:
  rotate: 5
  zones:
    matrix:
      # fix placement on kicad
      anchor.shift: [50, -150]
      key:
        tags: [switch]
        padding: 1ky
        spread: 1kx
      columns:
        outer:
          rows:
            num.skip: true
            mod.skip: true
          key:
            column_net: row0
        pinky:
          rows:
            mod.skip: true
          key:
            origin: [0, 8]
            column_net: row1
        ring:
          rows:
            mod.skip: true
          key:
            origin: [0, 8]
            stagger: 0.66ky
            splay: -5
            column_net: row2
        middle:
          key:
            stagger: 0.33ky
            column_net: row3
          rows:
            mod:
              column_net: row1
        index:
          key:
            stagger: -0.33ky
            column_net: row4
          rows:
            mod:
              column_net: row2
        inner:
          rows:
            mod.skip: true
          key:
            stagger: -2.5
            column_net: row5
      rows:
        mod:
          row_net: col4
          tags: [switch_bottom]
        bottom:
          row_net: col3
          tags: [switch_top]
        home:
          row_net: col2
          tags: [switch_bottom]
        top:
          row_net: col1
          tags: [switch_top]
        num:
          row_net: col0
          tags: [switch_bottom]
    thumbs:
      anchor:
        ref: matrix_middle_home
        shift: [38, -44]
      key:
        tags: [switch]
        padding: 1ky
        spread: 1kx
      columns:
        layer:
          key:
            splay: -15
            column_net: row3
        space:
          key:
            width: 1.5kx
            splay: 75
            shift: [13-kx, -3]
            column_net: row4
            tags: [switch_space]
      rows:
        cluster:
          row_net: col4
    scrollwheel:
      anchor:
        ref: matrix_inner_bottom
      columns:
        scrollwheel:
          key:
            tags: [scrollwheel]
            shift: [kx+mcu_padding-1.25, 0]
            column_net: row5
            width: scrollwheel_width
            height: scrollwheel_height
      rows:
        scrollwheel:
          row_net: col4
    mcu:
      anchor:
        ref: matrix_inner_num
      columns:
        mcu:
          key:
            tags: [mcu]
            width: mcu_height  # footprint width/height unintuitive
            height: mcu_width
            rotate: -90
            shift: [kx+mcu_padding, -mcu_width/2-0.3]
    screw_top_left:
      anchor:
        ref.aggregate.parts: [matrix_ring_num, matrix_ring_top]
        shift: [-11, 0]
      columns.screw.key.tags: [screw]
    screw_top_right:
      anchor:
        ref.aggregate.parts: [matrix_index_num, matrix_inner_num, matrix_index_top, matrix_inner_top]
      columns.screw.key.tags: [screw]
    screw_bottom_left:
      anchor:
        ref.aggregate.parts: [matrix_outer_home, matrix_outer_bottom, matrix_pinky_home, matrix_pinky_bottom]
      columns.screw.key.tags: [screw]
    screw_bottom_right:
      anchor:
        ref.aggregate.parts: [matrix_index_bottom, matrix_index_mod]
        shift: [-0.5kx, 0]
      columns.screw.key.tags: [screw]
    screw_thumb:
      anchor:
        ref.aggregate.parts: [thumbs_layer_cluster, thumbs_space_cluster]
        shift: [9, 7]
      columns.screw.key.tags: [screw]
outlines:
  board:
    - what: polygon
      operation: stack
      fillet: 2
      points:
        - ref: matrix_outer_home
          shift: [-0.5px, -0.5py]
        - ref: matrix_outer_home
          shift: [-0.5px, 0.5py]
        - ref: matrix_outer_top
          shift: [-0.5px, 0.5py]
        - ref: matrix_pinky_num
          shift: [-0.5px, 0.5py]
        - ref: matrix_ring_num
          shift: [-0.5px, 0.5py]
        - ref: matrix_middle_num
          shift: [-0.5px, 0.5py]
        - ref: matrix_middle_num
          shift: [0.5px, 0.5py]
        - ref: matrix_inner_num
          shift: [0.5px, 0.5py]
        - ref: matrix_inner_num
          shift: [0.5px+mcu_padding+mcu_width+0.25, 0.5py]  
        - ref: matrix_inner_bottom
          shift: [0.5px+mcu_padding+mcu_width+0.25, -0.5py]
        - ref: thumbs_space_cluster
          shift: [0.5px, -0.5py]
        - ref: thumbs_space_cluster
          shift: [-0.5px, -0.5py]
        - ref: matrix_index_mod
          shift: [-0.5px, -0.5py]  
        - ref: matrix_pinky_bottom
          shift: [0.5px, -0.5py]
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

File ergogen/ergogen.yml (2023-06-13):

units:
  kx: cx  # cx=18
  ky: cy  # cy=17
  mbkx: 17.5
  mbky: 16.5
  padding: 2
  px: kx+padding
  py: ky+padding
  mcu_height: 34
  mcu_width: 18
  mcu_padding: 2
  scrollwheel_width: 17
  scrollwheel_height: 14
points:
  zones:
    matrix:
      # fix placement on kicad
      anchor.shift: [150, -200]
      key:
        tags: [switch]
        padding: 1ky
        spread: 1kx
      columns:
        outer2:
          rows:
            mod.skip: true
            bottom.skip: true
            home:
              bind: [0, 5, 0, 0]
              row_net: row0
            top.skip: true
            num.skip: true
          key.column_net: col0
        outer:
          rows:
            num.skip: true
            mod.skip: true
          key.column_net: col0
        pinky:
          rows:
            mod.skip: true
          key:
            splay: -5
            origin: [0, 8]
            column_net: col1
        ring:
          rows:
            mod.skip: true
          key:
            origin: [0, 8]
            stagger: 0.33ky
            splay: -5
            column_net: col2
        middle:
          key:
            stagger: 0.2ky
            column_net: col3
          rows:
            mod:
              column_net: col1
        index:
          key:
            stagger: -0.33ky
            column_net: col4
          rows:
            mod:
              column_net: col2
        inner:
          rows:
            mod.skip: true
          key:
            stagger: -2.5
            column_net: col5
      rows:
        mod:
          row_net: row4
        bottom:
          row_net: row3
        home:
          row_net: row2
        top:
          row_net: row1
        num:
          row_net: row0
    thumbs:
      anchor:
        ref: matrix_middle_home
        shift: [38, -45]
      key:
        tags: [switch]
        padding: 1ky
        spread: 1kx
      columns:
        layer:
          key:
            splay: -15
            column_net: col3
        space:
          key:
            width: 1.5kx
            splay: 75
            shift: [13-kx, -3]
            column_net: col4
      rows:
        cluster:
          row_net: row4
    scrollwheel:
      anchor:
        ref: matrix_inner_bottom
      columns:
        scrollwheel:
          key:
            tags: [scrollwheel]
            shift: [px, -4]
            column_net: col5
            width: scrollwheel_width
            height: scrollwheel_height
      rows:
        scrollwheel:
          row_net: row4
    mcu:
      anchor:
        ref: matrix_inner_num
      columns:
        mcu:
          key:
            tags: [mcu]
            width: mcu_height  # footprint width/height unintuitive
            height: mcu_width
            rotate: -90
            shift: [kx+mcu_padding, -mcu_width/2+1]
  rotate: 10
outlines:
  keys:
    - what: rectangle
      where: true
      fillet: 2
      size: [mbkx, mbky]
  raw:
    - what: rectangle
      where: true
      bound: true
      size: [px+5, py+5]
  fillet:
    - what: outline
      name: raw
      fillet: 2
  board:
    - what: polygon
      operation: stack
      # fillet: 2
      points:
        - ref: matrix_outer2_home
          shift: [-0.5px, -0.5py]
        - ref: matrix_outer2_home
          shift: [-0.5px, 0.5py]
        - ref: matrix_outer_top
          shift: [-0.5px, 0.5py]
        - ref: matrix_pinky_num
          shift: [-0.5px, 0.5py]
        - ref: matrix_ring_num
          shift: [-0.5px, 0.5py]
        - ref: matrix_middle_num
          shift: [-0.5px, 0.5py]
        - ref: matrix_middle_num
          shift: [0.5px, 0.5py]
        - ref: matrix_inner_num
          shift: [0.5px, 0.5py]
        - ref: matrix_inner_num
          shift: [0.5px+mcu_padding+mcu_width+1, 0.5py]  
        - ref: matrix_inner_bottom
          shift: [0.5px+mcu_padding+mcu_width+1, -0.5py]
        - ref: thumbs_space_cluster
          shift: [0.5px, -0.5py]
        - ref: thumbs_space_cluster
          shift: [-0.5px, -0.5py]
        - ref: matrix_index_mod
          shift: [-0.5px, -0.5py]
        - ref: matrix_index_mod
          shift: [-0.5px, -0.5py]
        - ref: matrix_outer_bottom
          shift: [-0.5px, -0.5py]
pcbs:
  left:
    outlines.main.outline: board
    footprints:
      choc_hotswap:
        what: choc
        where: switch
        params:
          keycaps: true
          reverse: true
          hotswap: true
          from: "{{column_net}}"
          to: "{{colrow}}"
      diode:
        # TODO diode without throughhole?
        what: diode
        where: [switch]
        params:
          from: "{{colrow}}"
          to: "{{row_net}}"
        adjust.shift: [0, -5]
      scrollwheel:
        what: scrollwheel
        where: [scrollwheel]
        params:
          from: col5
          to: row4
          A: ENCB
          B: GND
          C: ENCA
          D: undefined
      scroll_diode:
        # TODO diode without throughhole
        what: diode
        where: [scrollwheel]
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

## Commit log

2023-06-04 button placement
2023-06-04 place some components on pcb
2023-06-04 work on button placement
2023-06-05 stagger and button placement
2023-06-08 remove index mod button
2023-06-12 define row and column net for switches
2023-06-13 rotate scrollwheel, fix outline
    [ergogen.yml]
2023-06-17 add diodes without through_holes
2023-06-18 use vias for diodes
2023-06-18 icnr. niceview distance for more battery space
2023-07-01 rotary legs removed + diode placement
2023-07-02 refine board polygon
2023-07-02 reposition encoder
2023-07-02 position diodes close to pad
2023-07-02 move up outer2 button
2023-07-02 switch and battery connection
2023-07-05 fix scroll wheel net
    [config.yaml]
2023-07-05 swap row and col pins
    [config.yaml]
2023-07-07 move diodes below keys
2023-07-07 add screw holes
2023-07-07 add plexiglas holes and move reset
    [config.yaml]
2023-07-09 rotate switches and adjust components to rotated switches
    commit d4ba6b622321e3bd7a7089699f45bbde7e819468
    Author: daniel <github@dbauer.me>
    Date: Sun Jul 9 12:29:10 2023 +0200
    adjust screw holes
    commit 41602ad8a8b55815b8c0b4ff7b805927a1cf0c3f
    Author: daniel <github@dbauer.me>
    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
2023-07-09 rotate scroll diode
2023-07-09 mirror switches and place diodes
2023-07-09 add mcu+batt labels to back of board
2023-07-09 fix mcu jumper net
    [config.yaml]
2023-07-09 text saying where to solder
2023-07-10 swap jumpers side to solder-on-back
    [config.yaml]
2023-07-10 re-add square around nicenano raw pin, but only on relevant side
2023-07-11 move diodes to center
2023-07-16 group diodes together
2023-07-16 adjust screw holes to new staggering
2023-07-17 screw hole sizes
2023-07-17 schematic overview
2023-07-18 change prototype image
2023-07-18 fixed some drc problems Squashed commit of the following:
    commit fc0171f96f06824f930dc5825498fa5e5ecf1060
    Date: Tue Jul 18 11:26:57 2023 +0200
    reversible slider
    commit 837158be306a0aa2e166f52b0d32387ab34f280f
    Date: Tue Jul 18 10:56:47 2023 +0200
    make hole footprints plated
    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
    [keyboard.kicad_pcb]
2023-07-18 define screw holes as points
2023-07-18 remove unused outlines
    [keys.dxf, raw.dxf]
2023-07-18 incr. switchplate tolerance around scrollwheel
    [switchplate.dxf, switchplate.kicad_pcb]
2023-07-18 add step files
    [keyboard.step, switchplate.step]
2023-07-19 kicad 7.0.6
    [keyboard.kicad_pcb, switchplate.kicad_pcb]
2023-07-19 add missing connection
    [keyboard-B_Cu.gbl, keyboard-B_Mask.gbs, keyboard-B_Paste.gbp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]
2023-07-19 add ground vias
    [keyboard-B_Cu.gbl, keyboard-B_Mask.gbs, keyboard-B_Paste.gbp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]
2023-07-19 switchplate distances
    [switchplate.dxf, switchplate.kicad_pcb, switchplate.step]
2023-07-19 add more ground vias
    [keyboard-B_Cu.gbl, keyboard-B_Mask.gbs, keyboard-B_Paste.gbp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]
2023-07-19 add order pcb number
    [keyboard-B_Cu.gbl, keyboard-B_Mask.gbs, keyboard-B_Paste.gbp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]
2023-07-20 diode direction
2023-07-29 switchplate stl
    [switchplate.stl]
2023-07-29 zmk config track main head
2023-07-30 cleanup pcb folder
    [board.dxf, keyboard.kicad_pcb, keyboard.step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]
2023-07-30 images and BOM
2023-07-30 3d printed case
    [case.dxf, case.f3z, case_left.stl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]
2023-07-30 3d printed case image sizes
2023-07-30 case BOM
2023-08-02 add mcu cover
    [mcu_cover.f3z, mcu_cover.stl]
2023-08-05 Squashed commit of the following:
    commit bb18cddcc8a03dbf4a5a163c8480892c78f4e76d
    Date: Sat Aug 5 11:43:33 2023 +0200
    update gerbers
    commit df5ee882de9ff45955de45abaf159e16f07e81d5
    Date: Sat Aug 5 11:43:15 2023 +0200
    pcb render
    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
    [keyboard-B_Cu.gbl, keyboard-B_Mask.gbs, keyboard-B_Paste.gbp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]
2023-08-12 actions: ergogen (#1)
    * actions: ergogen
    * Update ergogen.yaml
    * Update ergogen.yaml
    * Update ergogen.yaml
    * Update ergogen.yaml
    * Update ergogen.yaml
    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
2024-02-10 move corax56 in own folder
    [board.dxf, case.dxf, case.f3z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]
2024-02-10 corax54 pcbs
    [board.dxf, case.dxf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]
2024-03-26 case stls
    [bottom_left.stl, bottom_right.stl]
2024-03-29 clean pcb folder
    [keyboard.step, switchplate.step]
2024-03-29 add switchlate step file
    [switchplate.step]
2024-03-30 pcb ordering
